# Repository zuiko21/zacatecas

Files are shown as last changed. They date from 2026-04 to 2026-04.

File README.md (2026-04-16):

# Zacatecas
Chihuahua-based 65C02 SBC with integrated peripherals (LCD text screen, microSD card reader, 8-key pad)

## Specs

- 65C02 CPU at 1 MHz
- 32 KiB RAM
- 16 KiB ROM
- VIA 65C22 (Versatile Interface Adapter)
- 16x2 LCD text screen (HD44780-based, 4-bit parallel interface) with software-controlled backlight
- microSD card reader (_bit-banged_ SPI)
- Piezo buzzer (programmable thru VIA outputs `PB7` and `CB2`)
- Independent LED output, plus software-controlled microSD card activity LED
- _nanoLink_ input for card-less boot and development
- _SS22_ synchronous serial port (developed from a [6502.org](https://6502.org/forum/viewtopic.php?p=19484) idea by Garth Wilson and Samuel Falvo)

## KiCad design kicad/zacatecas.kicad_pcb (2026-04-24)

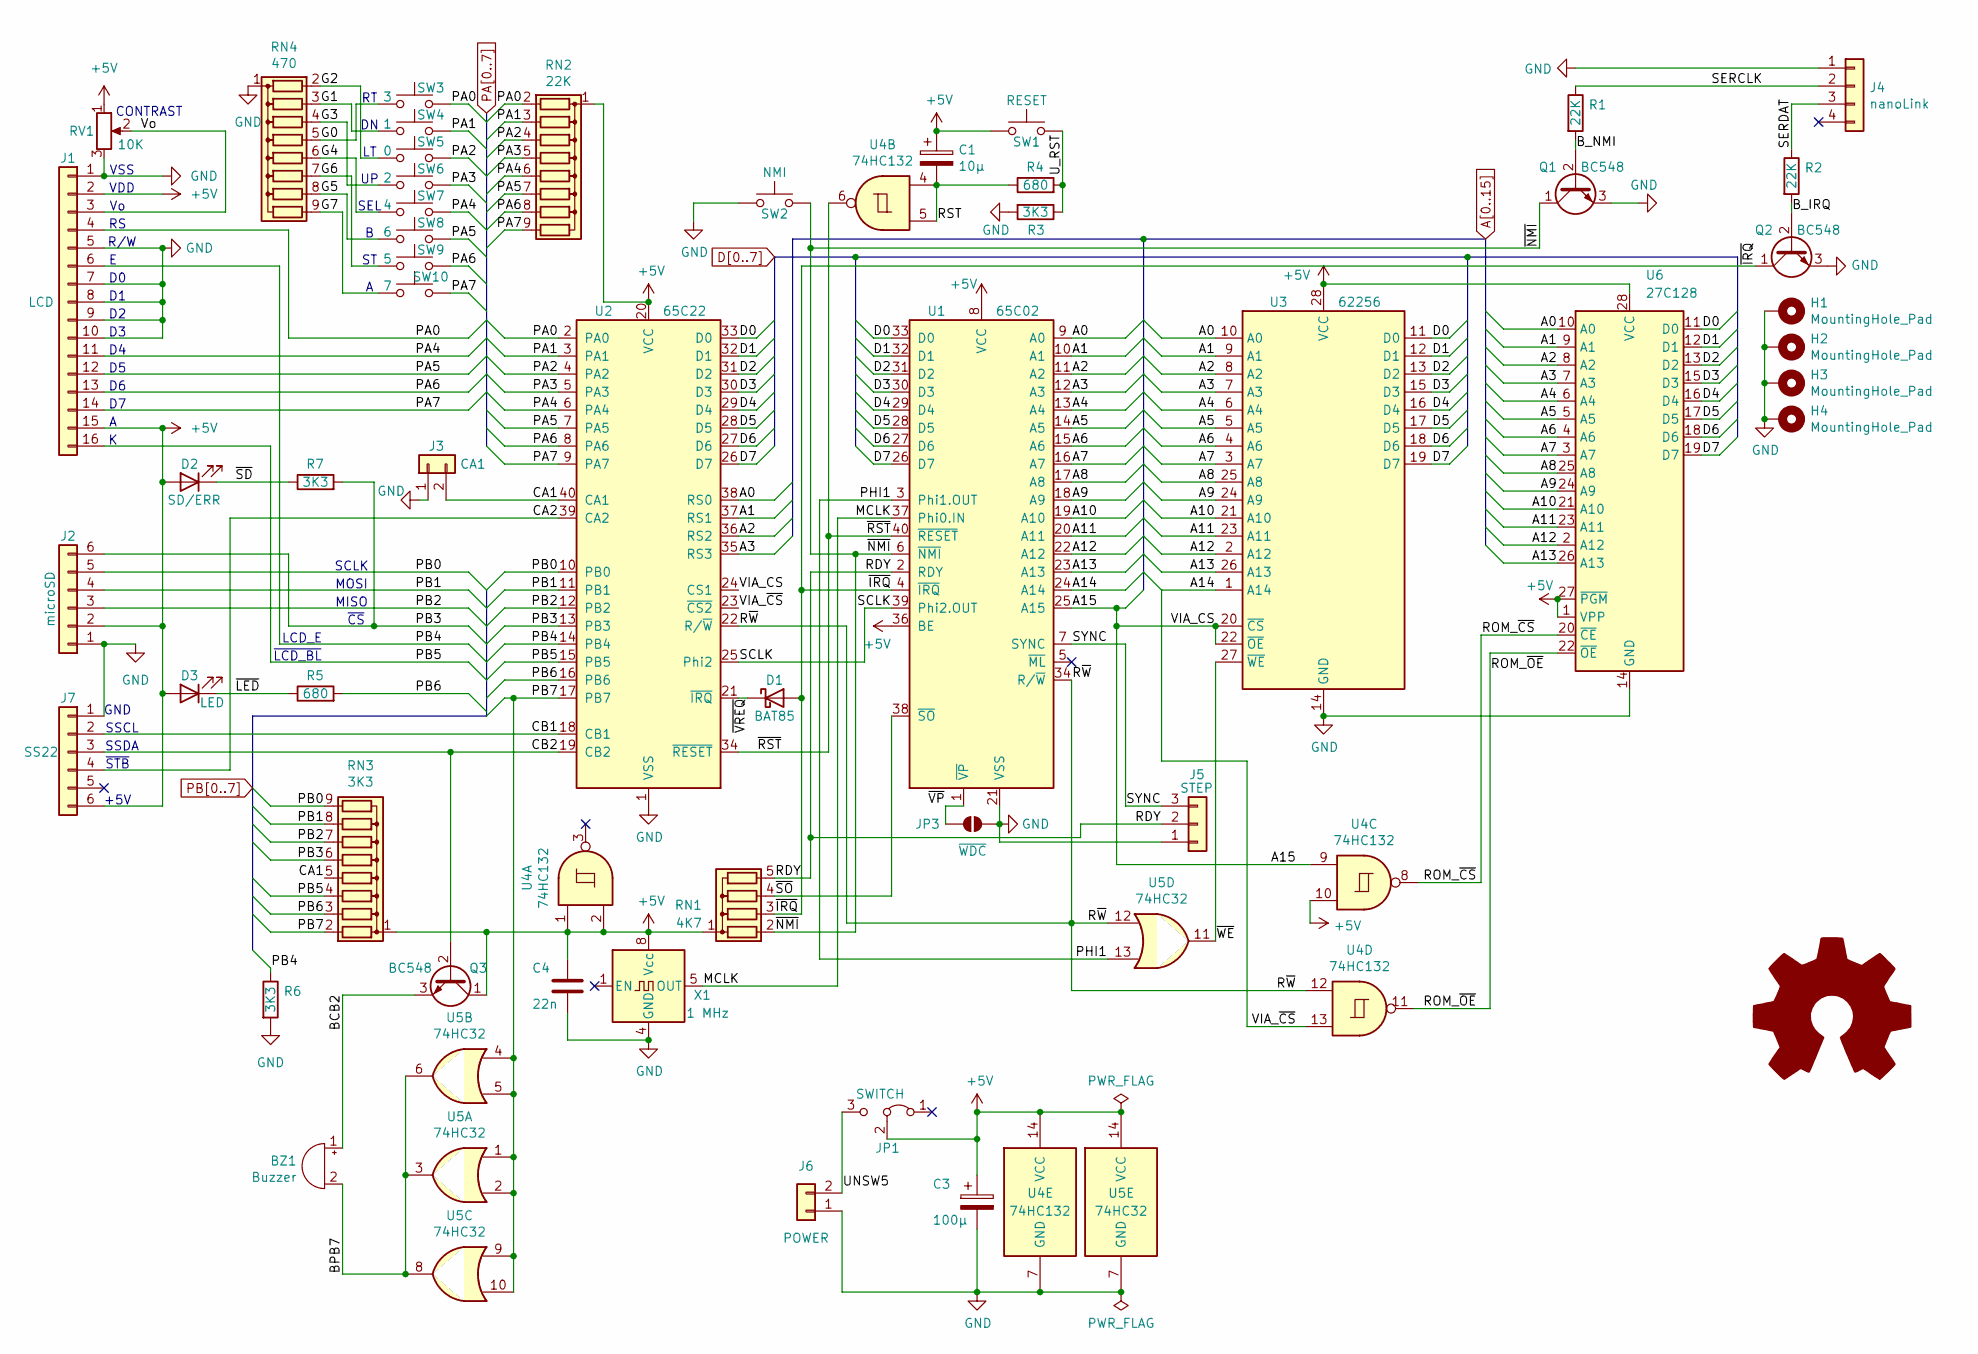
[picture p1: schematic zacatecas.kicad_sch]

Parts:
BZ1: Buzzer; Buzzer_12x9.5RM7.6
C1: 10µ; CP_Radial_D4.0mm_P1.50mm
C3: 100µ; CP_Radial_D4.0mm_P1.50mm
C4: 22n; C_Rect_L7.2mm_W2.5mm_P5.00mm_FKS2_FKP2_MKS2_MKP2
D1: BAT85; D_DO-35_SOD27_P2.54mm_Vertical_KathodeUp
D2: SD/ERR; LED_D3.0mm
D3: LED; LED_D3.0mm
H1, H2, H3, H4: MountingHole_Pad; MountingHole_3.2mm_M3_DIN965_Pad
J1: LCD; PinHeader_1x16_P2.54mm_Vertical
J2: microSD; PinSocket_1x06_P2.54mm_Vertical
J3: CA1; PinHeader_1x02_P2.54mm_Vertical
J4: nanoLink; PinHeader_1x04_P2.54mm_Vertical
J5: STEP; PinHeader_1x03_P2.54mm_Vertical
J6: POWER; JST_EH_S2B-EH_1x02_P2.50mm_Horizontal
J7: SS22; PinHeader_1x06_P2.54mm_Vertical
JP1: SWITCH; PowerSwitch
JP3: ~{WDC}; SolderJumper-2_P1.3mm_Open_RoundedPad1.0x1.5mm
LOGO1: Logo_Open_Hardware_Large; OSHW-Symbol_8.9x8mm_SilkScreen
Q1, Q2, Q3: BC548; TO-92_Inline
R1, R2: 22K; R_Axial_DIN0207_L6.3mm_D2.5mm_P2.54mm_Vertical
R3, R6, R7: 3K3; R_Axial_DIN0207_L6.3mm_D2.5mm_P2.54mm_Vertical
R4, R5: 680; R_Axial_DIN0207_L6.3mm_D2.5mm_P2.54mm_Vertical
RN1: 4K7; R_Array_SIP5
RN2: 22K; R_Array_SIP9
RN3: 3K3; R_Array_SIP9
RN4: 470; R_Array_SIP9
RV1: 10K; Potentiometer_Piher_PT-6-V_Vertical
SW1: RESET; SW_PUSH_6mm
SW2: NMI; SW_PUSH_6mm
SW3: 3; SW_PUSH_6mm
SW4: 1; SW_PUSH_6mm
SW5: 0; SW_PUSH_6mm
SW6: 2; SW_PUSH_6mm
SW7: 4; SW_PUSH_6mm
SW8: 6; SW_PUSH_6mm
SW9: 5; SW_PUSH_6mm
SW10: 7; SW_PUSH_6mm
U1: 65C02; DIP-40_W15.24mm_Socket
U2: 65C22; DIP-40_W15.24mm_Socket
U3: 62256; DIP-28_W15.24mm_Socket
U4: 74HC132; DIP-14_W7.62mm_Socket
U5: 74HC32; DIP-14_W7.62mm_Socket
U6: 27C128; DIP-28_W15.24mm_Socket
X1: 1 MHz; Oscillator_DIP-8

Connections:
+5V: C1.1, C3.1, C4.1, D2.2 (A), D3.2 (A), J1.2, J1.15, J2.2, J7.6, JP1.2 (C), Q3.1 (C), RN1.1 (common), RN2.1 (common), RN3.1 (common), RV1.1, SW1.2, U1.8 (VCC), U1.36 (BE), U2.20 (VCC), U3.28 (VCC), U4.1, U4.2, U4.10, U4.14 (VCC), U5.14 (VCC), U6.1 (VPP), U6.27 (~PGM), U6.28 (VCC), X1.8 (Vcc)
/BCB2: BZ1.1 (-), Q3.3 (E)
/BPB7: BZ1.2 (+), U5.3, U5.6, U5.8
/B_IRQ: Q2.2 (B), R2.2
/B_NMI: Q1.2 (B), R1.2
/CA1: J3.2, RN3.5 (R4), U2.40 (CA1)
/CA2: J7.4, U2.39 (CA2)
/CB1: J7.2, U2.18 (CB1)
/CB2: J7.3, Q3.2 (B), U2.19 (CB2)
/G0: RN4.5 (R4), SW3.1
/G1: RN4.3 (R2), SW4.1
/G2: RN4.2 (R1), SW5.1
/G3: RN4.4 (R3), SW6.1
/G4: RN4.6 (R5), SW7.1
/G5: RN4.8 (R7), SW8.1
/G6: RN4.7 (R6), SW9.1
/G7: RN4.9 (R8), SW10.1
/MCLK: U1.37 (Phi0.IN), X1.5 (OUT)
/PHI1: U1.3 (Phi1.OUT), U5.13
/RDY: J5.2, RN1.5 (R4), U1.2 (RDY)
/ROM_~CS: U4.8, U6.20 (~CE)
/ROM_~OE: U4.11, U6.22 (~OE)
/RST: C1.2, R4.1, U4.4, U4.5
/R~W: U1.34 (R/~W), U2.22 (R/~W), U4.12, U5.12
/SCLK: U1.39 (Phi2.OUT), U2.25 (Phi2)
/SERCLK: J4.2, R1.1
/SERDAT: J4.3, R2.1
/SYNC: J5.3, U1.7 (SYNC)
/UNSW5: J6.2, JP1.3 (B)
/U_RST: R3.1, R4.2, SW1.1
/Vo: J1.3, RV1.2
/~IRQ: D1.2 (A), Q2.1 (C), RN1.3 (R2), U1.4 (~IRQ)
/~LED: D3.1 (K), R5.1
/~NMI: Q1.1 (C), RN1.2 (R1), SW2.2, U1.6 (~NMI)
/~RST: U1.40 (~RESET), U2.34 (~RESET), U4.6
/~SD: D2.1 (K), R7.1
/~SO: RN1.4 (R3), U1.38 (~SO)
/~VP: JP3.1 (A), U1.1 (~VP)
/~VREQ: D1.1 (K), U2.21 (~IRQ)
/~WE: U3.27 (~WE), U5.11
A0: U1.9 (A0), U2.38 (RS0), U3.10 (A0), U6.10 (A0)
A1: U1.10 (A1), U2.37 (RS1), U3.9 (A1), U6.9 (A1)
A2: U1.11 (A2), U2.36 (RS2), U3.8 (A2), U6.8 (A2)
A3: U1.12 (A3), U2.35 (RS3), U3.7 (A3), U6.7 (A3)
A4: U1.13 (A4), U3.6 (A4), U6.6 (A4)
A5: U1.14 (A5), U3.5 (A5), U6.5 (A5)
A6: U1.15 (A6), U3.4 (A6), U6.4 (A6)
A7: U1.16 (A7), U3.3 (A7), U6.3 (A7)
A8: U1.17 (A8), U3.25 (A8), U6.25 (A8)
A9: U1.18 (A9), U3.24 (A9), U6.24 (A9)
A10: U1.19 (A10), U3.21 (A10), U6.21 (A10)
A11: U1.20 (A11), U3.23 (A11), U6.23 (A11)
A12: U1.22 (A12), U3.2 (A12), U6.2 (A12)
A13: U1.23 (A13), U3.26 (A13), U6.26 (A13)
A14: U1.24 (A14), U2.23 (~CS2), U3.1 (A14), U4.13
A15: U1.25 (A15), U2.24 (CS1), U3.20 (~CS), U3.22 (~OE), U4.9
D0: U1.33 (D0), U2.33 (D0), U3.11 (D0), U6.11 (D0)
D1: U1.32 (D1), U2.32 (D1), U3.12 (D1), U6.12 (D1)
D2: U1.31 (D2), U2.31 (D2), U3.13 (D2), U6.13 (D2)
D3: U1.30 (D3), U2.30 (D3), U3.15 (D3), U6.15 (D3)
D4: U1.29 (D4), U2.29 (D4), U3.16 (D4), U6.16 (D4)
D5: U1.28 (D5), U2.28 (D5), U3.17 (D5), U6.17 (D5)
D6: U1.27 (D6), U2.27 (D6), U3.18 (D6), U6.18 (D6)
D7: U1.26 (D7), U2.26 (D7), U3.19 (D7), U6.19 (D7)
GND: C3.2, C4.2, H1.1, H2.1, H3.1, H4.1, J1.1, J1.5, J1.7, J1.8, J1.9, J1.10, J2.1, J3.1, J4.1, J5.1, J6.1, J7.1, JP3.2 (B), Q1.3 (E), Q2.3 (E), R3.2, R6.2, RN4.1 (common), RV1.3, SW2.1, U1.21 (VSS), U2.1 (VSS), U3.14 (GND), U4.7 (GND), U5.7 (GND), U6.14 (GND), X1.4 (GND)
PA0: J1.4, RN2.2 (R1), SW3.2, U2.2 (PA0)
PA1: RN2.3 (R2), SW4.2, U2.3 (PA1)
PA2: RN2.4 (R3), SW5.2, U2.4 (PA2)
PA3: RN2.5 (R4), SW6.2, U2.5 (PA3)
PA4: J1.11, RN2.6 (R5), SW7.2, U2.6 (PA4)
PA5: J1.12, RN2.7 (R6), SW8.2, U2.7 (PA5)
PA6: J1.13, RN2.8 (R7), SW9.2, U2.8 (PA6)
PA7: J1.14, RN2.9 (R8), SW10.2, U2.9 (PA7)
PB0: J2.5, RN3.9 (R8), U2.10 (PB0)
PB1: J2.4, RN3.8 (R7), U2.11 (PB1)
PB2: J2.3, RN3.7 (R6), U2.12 (PB2)
PB3: J2.6, R7.2, RN3.6 (R5), U2.13 (PB3)
PB4: J1.6, R6.1, U2.14 (PB4)
PB5: J1.16, RN3.4 (R3), U2.15 (PB5)
PB6: R5.2, RN3.3 (R2), U2.16 (PB6)
PB7: RN3.2 (R1), U2.17 (PB7), U5.1, U5.2, U5.4, U5.5, U5.9, U5.10

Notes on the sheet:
~{LCD_BL}
VSS
MISO
SEL
SSDA
CONTRAST
SSCL
+5V
~{CS}
~{STB}
VDD
SCLK
LCD_E
GND
MOSI
R/W

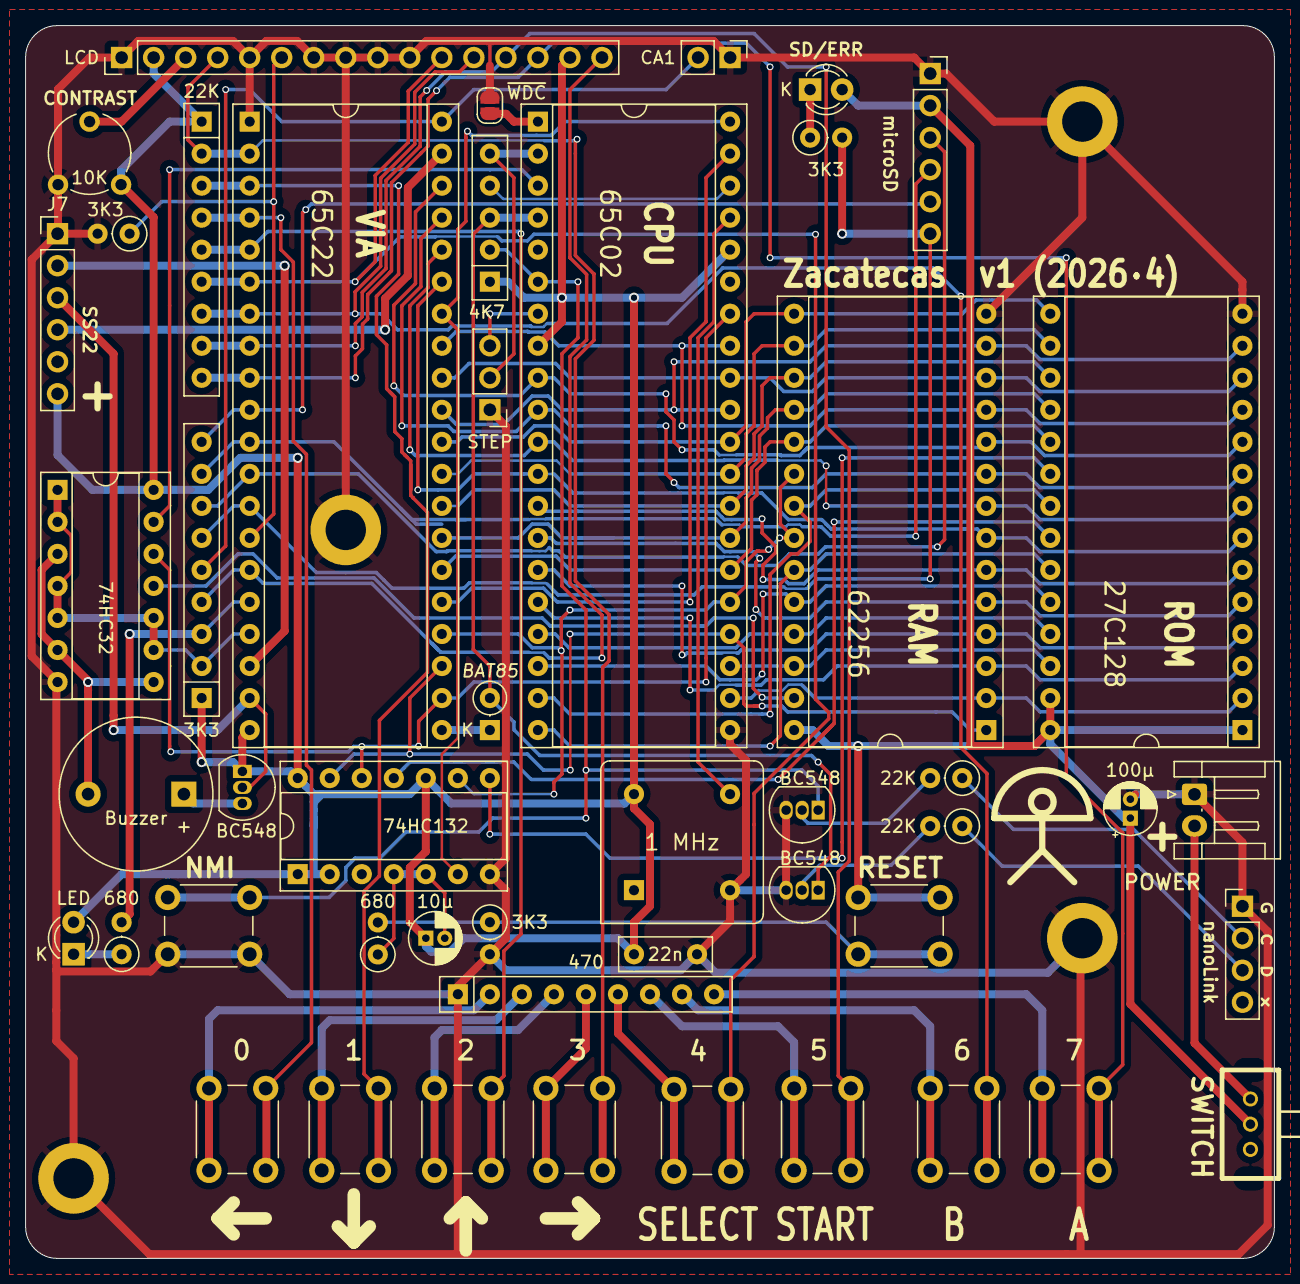
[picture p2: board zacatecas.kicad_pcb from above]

Board: 2 copper layers, 99.1 x 97.8 mm, 53 parts (1 on the bottom side), 81 nets.

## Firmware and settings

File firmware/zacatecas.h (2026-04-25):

; **************************************
; *** Zacatecas hardware definitions ***
; **************************************
#ifndef	SPEED
#define		SPEED	1000000
#endif

; LCD at PB4...PB5, BL is active LOW
#define		LCD_BLON	%11011111
#define		LCD_BLOFF	%00100000
#define		LCD_EN		%00010000
#define		LCD_DIS		%11101111

; LCD data at PA4...PA7, RS at PA0
#define		LCD_RS		%00000001
#define		LCD_DATA	%11110000

; SD interface at PB0...PB3, CS is active LOW
#define		SD_EN		%11110111
#define		SD_DIS		%00001000
#define		SD_MISO		%00000100
#define		SD_MOSI		%00000010
#define		SD_CLK		%00000001

; Emilio's LED at PB6, active LOW
#define		LED_ON		%10111111
#define		LED_OFF		%01000000

; key pad at PA0...PA7, all active LOW
#define		PAD_RT		%00000001
#define		PAD_DN		%00000010
#define		PAD_LT		%00000100
#define		PAD_UP		%00001000
#define		PAD_SEL		%00010000
#define		PAD_B		%00100000
#define		PAD_ST		%01000000
#define		PAD_A		%10000000

; *** VIA constants ***
#define	IORB	0
#define	IORA	1
#define	DDRB	2
#define	DDRA	3
#define	T1CL	4
#define	T1CH	5
#define	T1LL	6
#define	T1LH	7
#define	T2CL	8
#define	T2CH	9
#define	VSR		10
#define	ACR		11
#define	PCR		12
#define	IFR		13
#define	IER		14
#define	NHRA	15

; ****************************
; *** standard definitions ***
	fw_irq	= $0200
	fw_nmi	= $0202
	ticks	= $0206
	gamepad	= $0226
	
	t1ct	= (SPEED/250)-2	; 250 Hz interrupt at 1 MHz (or whatever) clock rate
; ****************************

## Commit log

2026-04-24 add KiCAD folder
    [zacatecas-B_Cu.gbl, zacatecas-B_Mask.gbs, zacatecas-B_Paste.gbp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]
2026-04-25 Add Emilio's LED definitions
2026-04-27 new header type and proper interrupt mask handling by LCD

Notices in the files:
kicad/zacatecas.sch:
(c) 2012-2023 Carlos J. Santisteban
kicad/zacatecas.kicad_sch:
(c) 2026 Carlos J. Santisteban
